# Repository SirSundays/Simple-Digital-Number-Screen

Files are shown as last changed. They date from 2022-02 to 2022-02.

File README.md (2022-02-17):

# Simple digital number screen

This project is ment to give a base for further development of a simple screen that just shows a number. This can be used to show customers which one is next. It does not rely on any other third-party services. 

## Idea

A screen hangs somewhere prominent in a room. It has some sort of small computer attached running software to drive the display. A worker has a small controller that connects to the display (or rather the computer). With the controller he can control the number displayed.

## Solution

InAction

The GIF shows not the latest version. The clock is disabled by default and I removed all the letters so the splitflap is only going through all the numbers.

### Screen

I choose a 27 inch 1080p monitor that was under 200€. The only things really from interest where the size and good viewing angles.

### Computer

As a computer I choose the (now new) Raspberry Pi Zero 2. It definitly has enough horse power to run a little application to display numbers. 
It also runs the [RaspAP](https://raspap.com/ "RaspAP") software. Which makes the Raspberry Pi a small router. It is a bit overkill but works flawlessly. It just creates a WiFi Hotspot for the controller to connect to. So it is independend from other hardware.

### Number display software

I choose to write my own little software for that. More information can be found here:
[Link to the Readme](https://github.com/SirSundays/Simple-Digital-Number-Screen/tree/main/frontend%2Bserver "Link to the Readme")
The software is autostarted by the Raspberry. This article by Lucas Vogel helped with some best practices:
https://lucas-vogel.de/blog/perfect-electron/

### Controller

The controller consist of a ESP8266 with battery, a rotary encoder and a small display. All together in a 3d-printed housing. More information can be found here:
[Link to the Readme](https://github.com/SirSundays/Simple-Digital-Number-Screen/tree/main/controller "Link to the Readme")

## Background

This project was a short 2 day project for me. My professor got some money for this a couple of years ago but no one ever started this small project. I had some flex time now and so I just started working on it.  I liked to use skills of every tech area, this is really a Full Stack Project:
- Frontend Programming (JavaScript / HTML)
- Server Programming (Node.js)
- Server Administration (Autostart + RaspAP)
- Embedded Programming (ESP8266 / C++)
- Electronic Design (Yeah just attach some components directly to the Feather)
- CAD (Maybe just a little Box but hey atleast something)

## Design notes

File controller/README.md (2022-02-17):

# Controller

## Hardware
I used this components:
- Adafruit Feather Huzzah ESP8266
- Rotary Encoder with Button
- 128x64 OLED I2C OLED Display
- 2000mAh 1C LiPo Battery
- Micro-USB Breakout (just for charging in the case (I was to lazy to design the case so the Feather sits perfectly to charge it directly))
- Some M3 (2x longer ones for the Rotary Encoder + 2x 8mm for the case) and M2 (2x 10mm for the display) bolts and nuts
- Some hook up wire (I just assembled nearly everything outside the case and jammed it all in the little box)

Here you can see the schematic on a breadboard. Not hard. If it fits you can plug in the LiPo directly into the feather without the need of the BAT-Pin.

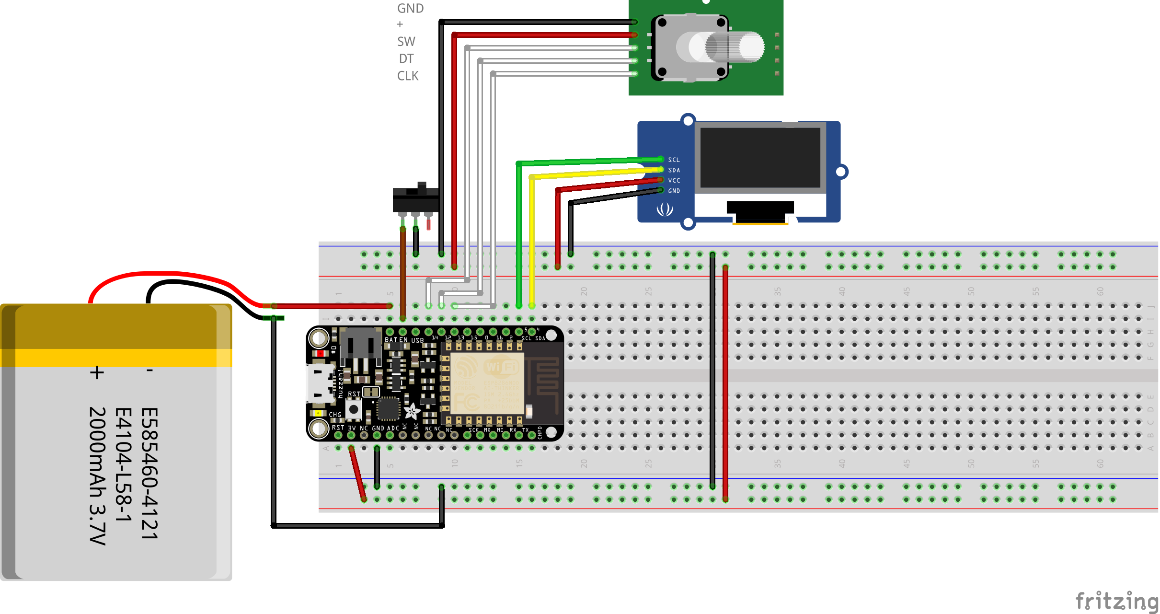
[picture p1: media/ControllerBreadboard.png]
ControllerBreadboard


## Software / Firmware

The firmware for the feather can be found in the `Controller`-Folder. It can be opened with the Arduino IDE. It uses the following non-standard libraries:
- [Ai Esp32 Rotary Encoder](https://www.arduino.cc/reference/en/libraries/ai-esp32-rotary-encoder/ "Ai Esp32 Rotary Encoder")
- [U8g2](https://www.arduino.cc/reference/en/libraries/u8g2/ "U8g2")

Right now the interface is in german, but there are only two words to translate that should be doable (Nächste  -> Next | Aktuell -> Current).

The ESP8266 will first try to connect to the WiFi of the Raspberry. The SSID and Password can be changed in code. While connecting a blinking dot is displayed on the display. After connecting it will get the currently displayed number from the Node.js server. You can then set the next number with the rotary encoder either by rotating until you get to the desired number or incrementing one by a short press. To send the new number you have to long press the button for atleast half a second. If you let go of the button the new number will be send to the server. While doing so the controller display reacts accordingly. The minimum number to be displayed is 0 and the max number is 9999.

ControllerDisplay02

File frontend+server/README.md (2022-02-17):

# Frontend & Server

This application uses Electron to setup a server and a frontend running in chromium at the same time. Works on nearly all platforms. (Of course also on the Raspberry Pi Zero 2)
The frontend and the server are communicating over Electrons internal process communication bus. The server also sets up 2 routes that can be accessed by other devices in the same network by calling the server over http. 

### Server
The Node-Server of Electron runs from the index.js. It includes all the windows configuration for the chromium browser and handles incoming http requests. These are the two available routes:
1. ` HTTP GET /` | Returns a JSON String. The currently displayed number can be found with the key `displayNumber`.
1.  `HTTP POST /:number` | Returns a JSON String. The currently displayed number can be found with the key `displayNumber`.  `:number` has to be replaced by the number that should be displayed. If it´s not a number, `0` will be displayed. If it is bigger then `10000` or smaller then `0`, also `0` will be displayed.

If the application crashes it will automatically restart. The Server is running on port `3000`.

### Frontend (browser folder)
The frontend shows the current number in a splitflap like display. For that it is using this library from Roosterfish called Fallblatt:
https://github.com/Roosterfish/fallblatt
The code can also be found in the `./browser/src` folder.
I removed all characters, excluding numbers and a colon.
In the index.js two options are present:
- `hideCursor` (default true)
- `activateTime` (default false)

`activateTime` is turned off by default because the used Raspberry Pi Zero 2 cannot keep track of the when it is turned of. This is because of the lack of a RTC. If you would connect it to a internet connected network it would get the actual time by calling an NTP Server. Because I´m using the Raspberry as a Hotspot I´m not able to utilize this.

ControllerDisplay01

### Getting Started

1.  Go into the `frontend+server`-folder
1.  Execute `npm i` to install all dependencies
1.  Execute `npm start` to get the application up and running

I decided to not build the actual application with Electron but rather just execute `npm start` on startup of the Raspberry. This makes the application much more platform independend. With a bigger application, building would make more sense.

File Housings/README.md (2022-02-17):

# Housings

In this folder you can find the 3d prints I used and created for this little project.

### Raspberry Pi Zero Case

I found this case on Thingiverse:
https://www.thingiverse.com/thing:2437095

Case and Photo by Superrei (https://cdn.thingiverse.com/renders/36/39/ba/41/18/c9af92d9b76d693b5f3230c74f3a3ab6_preview_featured.jpg "Case and Photo by Superrei")

I modified it and added a little bridge with a hole so you can mount it at the back of the used monitor at one of the VESA mounting points.
The file is: Rpi-Zero-Case-Clim - Modified

### Controller

The other two files are the controller box. It consist of a box an lid. The lid can be secured but I would advise to add another hole on the other side of the box to secure it with a third screw.
Otherwise there are just holes for all the components.
There is no real specific place for every component inside the box. I just cramped it all in there.
My assembly process:
1.  Put in the battery
1.  Put in the USB Breakout and screw it in place. I added some solder to the solder points beforehand.
1.  Put in the button. Also added some solder there before.
1. Put in the ESP8266 with all the other components already attached.
1.  Soldered all the other components carefully in place. Watch out not to hit the battery with the soldering Iron.
1.  Plugged in the battery last. 
1.  Pushed the lit on. It is easier when the hook up wires are a bit shorter to be honest.

Is this ideal? No! This is just something so you can use it without some bare components in your hands. This can definitly done better.

Housings

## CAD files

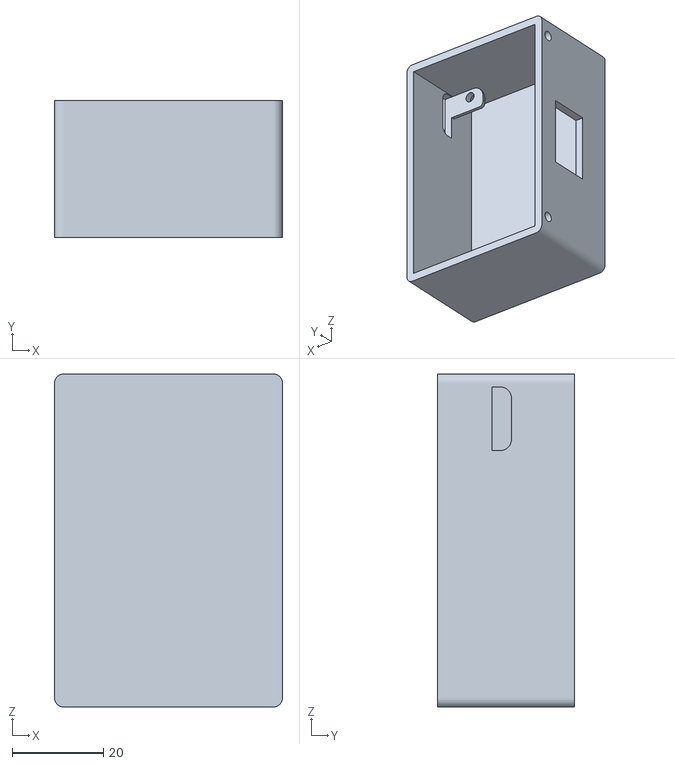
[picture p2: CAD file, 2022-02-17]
Housings/Body - Counter Controller.stl
50.0 x 30.0 x 73.0

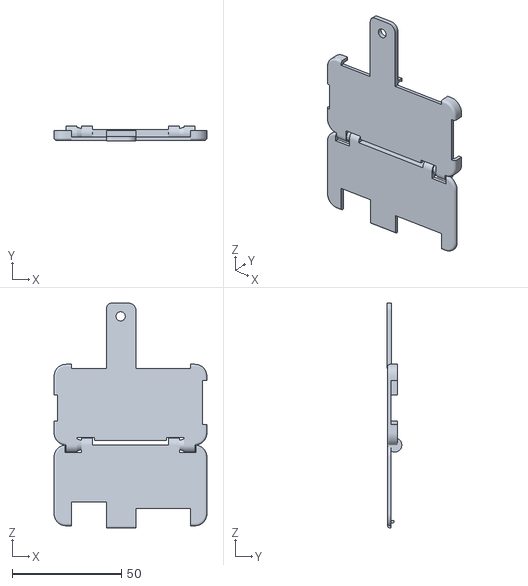
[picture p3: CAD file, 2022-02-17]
Housings/RPi-Zero-Case-Slim - Modified.stl
70.0 x 6.74 x 103.0

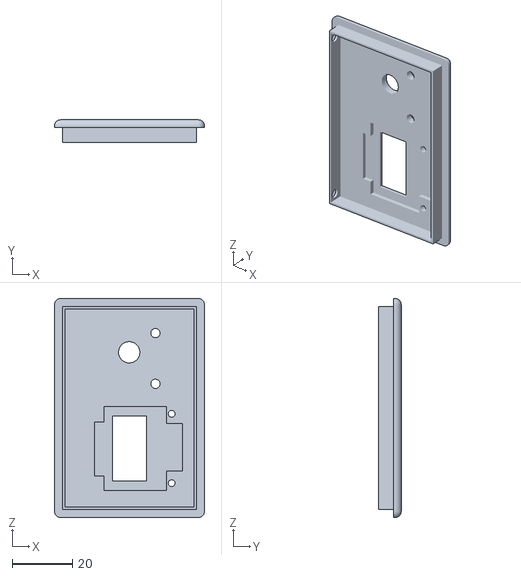
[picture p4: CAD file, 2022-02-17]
Housings/Cover - Counter Controller.stl
50.0 x 7.50 x 73.0

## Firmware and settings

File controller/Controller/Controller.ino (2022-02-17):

#include "AiEsp32RotaryEncoder.h"
#include "Arduino.h"
#include <stdlib.h>

#include <U8g2lib.h>
#include <Wire.h>

#include <ESP8266WiFi.h>
#include <ESP8266HTTPClient.h>

U8G2_SSD1306_128X64_NONAME_F_SW_I2C u8g2(U8G2_R0, /* clock=*/ SCL, /* data=*/ SDA, /* reset=*/ U8X8_PIN_NONE);

const char *ssid = "Tafel-Counter";
const char *password = "ChangeMe";

String host = "10.3.141.1:3000";

#define ROTARY_ENCODER_A_PIN 13
#define ROTARY_ENCODER_B_PIN 12
#define ROTARY_ENCODER_BUTTON_PIN 14

#define ROTARY_ENCODER_VCC_PIN -1

#define ROTARY_ENCODER_STEPS 4

const int SHORT_PRESS_TIME = 500;
int lastState = HIGH;
int currentState;
unsigned long pressedTime  = 0;
unsigned long releasedTime = 0;

AiEsp32RotaryEncoder rotaryEncoder = AiEsp32RotaryEncoder(ROTARY_ENCODER_A_PIN, ROTARY_ENCODER_B_PIN, ROTARY_ENCODER_BUTTON_PIN, ROTARY_ENCODER_VCC_PIN, ROTARY_ENCODER_STEPS);

unsigned long acceletation = 100;
bool circleValues = false;
int minValue = 0;
int maxValue = 9999;

static unsigned long lastTimePressed = 0;

void rotary_onLongButtonClick()
{
  if ((WiFi.status() == WL_CONNECTED)) {

    WiFiClient client;
    HTTPClient http;

    Serial.print("[HTTP] begin...\n");
    // configure traged server and url
    http.begin(client, "http://" + host + "/" + rotaryEncoder.readEncoder()); //HTTP
    http.addHeader("Content-Type", "application/json");

    Serial.print("[HTTP] POST...\n");
    // start connection and send HTTP header and body
    int httpCode = http.POST("");

    // httpCode will be negative on error
    if (httpCode > 0) {
      // HTTP header has been send and Server response header has been handled
      Serial.printf("[HTTP] POST... code: %d\n", httpCode);

        const String& payload = http.getString();
        Serial.println("received payload:\n<<");
        Serial.println(payload);
        Serial.println(">>");
    } else {
      Serial.printf("[HTTP] POST... failed, error: %s\n", http.errorToString(httpCode).c_str());
    }

    http.end();

    delay(50);

    getCurrentNumber();

    rotaryEncoder.setEncoderValue(rotaryEncoder.readEncoder() + 1);
  }
}

void rotary_onShortButtonClick()
{
  rotaryEncoder.setEncoderValue(rotaryEncoder.readEncoder() + 1);
}

void rotary_loop()
{
  if (rotaryEncoder.encoderChanged())
  {
    u8g2.setCursor(9, 35);
    u8g2.printf("%04d", rotaryEncoder.readEncoder());
    u8g2.sendBuffer();
    Serial.print("Value: ");
    Serial.println(rotaryEncoder.readEncoder());
  }

  currentState = digitalRead(ROTARY_ENCODER_BUTTON_PIN);

  if (lastState == HIGH && currentState == LOW)       // button is pressed
    pressedTime = millis();
  else if (lastState == LOW && currentState == HIGH) { // button is released
    releasedTime = millis();

    long pressDuration = releasedTime - pressedTime;

    if ( pressDuration <= SHORT_PRESS_TIME && pressDuration != 0) {
      rotary_onShortButtonClick();
    } else {
      rotary_onLongButtonClick();
    }
  }

  lastState = currentState;
}

void setDisplayNormal() {
  u8g2.clear();

  u8g2.drawStr(4, 10, "Nachste:");
  u8g2.drawStr(68, 10, "Aktuell:");
  u8g2.sendBuffer();

  u8g2.setCursor(9, 35);
  u8g2.printf("%04d", rotaryEncoder.readEncoder());
  u8g2.sendBuffer();
}

uint16_t getCurrentNumber() {
  uint16_t currenltyDisplayedNumberServer = 0;
  
  WiFiClient client;
  HTTPClient http;

  Serial.print("[HTTP] begin...\n");
  // configure traged server and url
  http.begin(client, "http://" + host + "/"); //HTTP
  http.addHeader("Content-Type", "application/json");

  Serial.print("[HTTP] GET...\n");
  // start connection and send HTTP header and body
  int httpCode = http.GET();

  // httpCode will be negative on error
  if (httpCode > 0) {
    // HTTP header has been send and Server response header has been handled
    Serial.printf("[HTTP] GET... code: %d\n", httpCode);

    // file found at server
    if (httpCode == HTTP_CODE_OK) {
      const String& payload = http.getString();
      Serial.println("received payload:\n<<");
      Serial.println(payload);
      Serial.println(">>");
      currenltyDisplayedNumberServer = strtol(payload.substring(payload.lastIndexOf(':') + 1, payload.length() - 1).c_str(), NULL, 0);
      Serial.println(currenltyDisplayedNumberServer);
    }
  } else {
    Serial.printf("[HTTP] GET... failed, error: %s\n", http.errorToString(httpCode).c_str());
  }

  http.end();

  u8g2.setCursor(73, 35);
  u8g2.printf("%04d", currenltyDisplayedNumberServer);
  u8g2.sendBuffer();

  return currenltyDisplayedNumberServer;
}

void IRAM_ATTR readEncoderISR()
{
  rotaryEncoder.readEncoder_ISR();
}

void setup()
{
  Serial.begin(115200);

  u8g2.begin();
  u8g2.setFont(u8g2_font_timB10_tf);

  WiFi.begin(ssid, password);

  while (WiFi.status() != WL_CONNECTED) {
    u8g2.clear();
    delay(500);
    u8g2.drawStr(0, 5, ".");
    u8g2.sendBuffer();
    delay(500);
  }

  Serial.println("");
  Serial.print("Connected! IP address: ");
  Serial.println(WiFi.localIP());

  setDisplayNormal();

  rotaryEncoder.begin();
  rotaryEncoder.setup(readEncoderISR);
  rotaryEncoder.setBoundaries(minValue, maxValue, circleValues);
  rotaryEncoder.setAcceleration(acceletation);

  getCurrentNumber();
}

void loop()
{
  rotary_loop();
  delay(50);
}

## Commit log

2022-01-18 Number can now be presented
    API can be called to get the currently displayed number and to set a new number
2022-02-17 Rearranging + Documentation
    [Body - Counter Controller.stl, Cover - Counter Controller.stl, RPi-Zero-Case-Slim - Modified.stl]
